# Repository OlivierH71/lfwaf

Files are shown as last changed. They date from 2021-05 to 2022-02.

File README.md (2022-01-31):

# lfwaf
Literally "Lightest filter wheel and focuser". This project aim to design a complete system based on indy library, Arduino like controller and 3D prints in order to get the less heavy focuser and filter wheel for Newton astro-photography.

In parralel to the Arduino code, an indi driver is developped under ~/Projects/indi/examples/lfwaf. You can refer to https://indilib.org/develop/developer-manual/163-setting-development-environment.html for indi driver dev 
To call the inidiserver during devlopment, use "indiserver -v ~/Projects/indi/examples/lfwaf/lfwaf" and open an indi client, I used Kstars. From Kstars, use "Tools|Device|Device Manager", Select "Client Tab" and a connection to the host (usualy localhost) on port 7624.

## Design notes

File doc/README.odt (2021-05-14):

lightest_focuserwheel

This project has been highly inspired by astroberry-diy (https://github.com/rkaczorek/astroberry-diy) and indi-wheel (https://github.com/Blueshawk/indi-wheel) .

Objective is to have the lightest setup with a minimum of cables to command diy focuser and diy filter wheel. Indeed, astroberry-diy focuser is a great use of raspberry pi connections but you need a minimum of 8 wires from pi to motor driver (MS1,MS2,MS3, GND, VDD, STEP, DIR and RST) and potentially 2 additional wires to connect buttons. So you need to know how-to build a good reliable and plugable 10 pin wire. RJ45 is a good candidate but if you connect the 8 pins to an RJ45 female, link to the focuser with RJ45 cable, and, then, same from driver and buttons, it becomes a little bit messy to connect. Additionally, you could do the same for the Wheel and all this becomes a cable nightmare.

My first idea was to use one of the USB connection and a USB to Serial cable to an Arduino device. As a direct consequence this enable the project to:

- Connect from any indi machine (not only rasperry device)
- Use BlueTooth as an alternative to USB cable as BlueTooth is also “seen” from the system as a serial port. If, like me, you have an astro setup with too many wires, and risk to block the mount tracking, each wire saving is an increase chance to follow correctly the stars.

As the weight is key, I also wanted to design a “3D” box which contains all arduino hardware, ie, the 2 stepper motors drivers, the optional connections to buttons and the Arduino device. This came to a choice, either to use an onboard BlueTooth device (ESP32) or an external BlueTooth connection (HC-05 for example). I ended up to do a system which can work with both.

Option ESP32

Install ESP32 board in arduino IDE: https://randomnerdtutorials.com/installing-the-esp32-board-in-arduino-ide-mac-and-linux-instructions/

For security (in case of ESP32 is replaced by different system), I have downloaded the files and instructions in ESP32. Use only in case of instructions in previous link does not work.

I used the ESP32-CAM version because… I had one :) Additionnaly this is the smallest version available at cheap cost and, why not, find a future use of the Camera feature

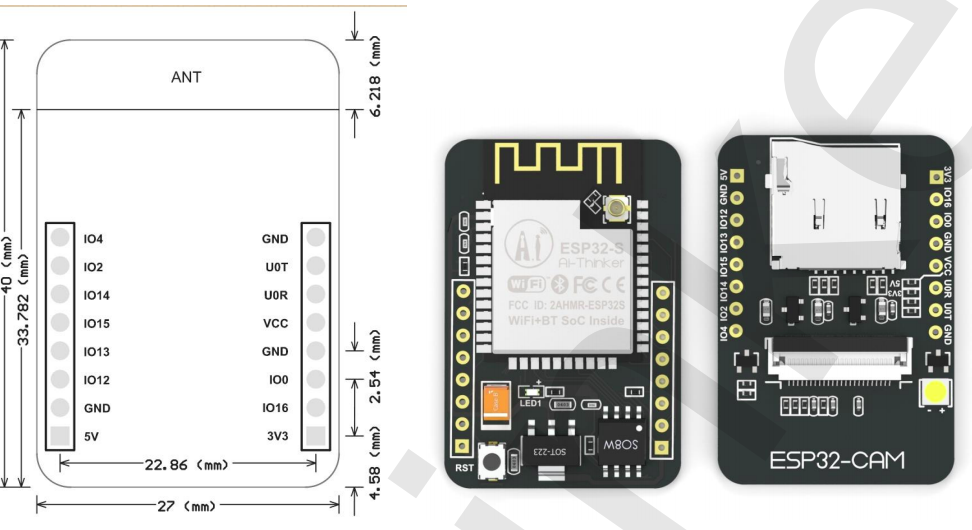
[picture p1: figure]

## The A4988 and stepper motor option

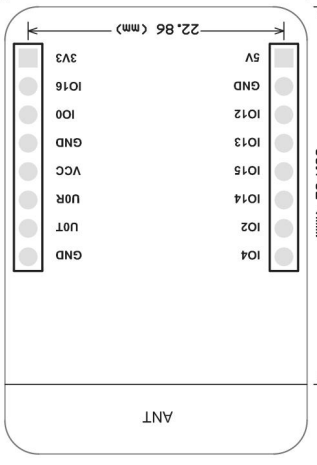
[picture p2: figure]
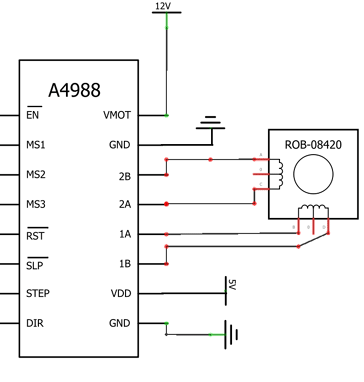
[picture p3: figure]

WARNING: Unlike what I initially thought, IO0 CANNOT BE USED. Connected to ground, this pin will put the ESP32 in Flashing mode.

The problem is the weight of the motors. A nema 17 weight is about 250g which, when installed at the end of my Newton telescope is really heavy, especially if you need two (one for the wheel and one for the focuser). Half a kilo does not deserve the “lightest” term.

Looking to different options, I found out that one of the lightest option I could find was a servo motor sg90 hacked to be able to turn endlessly, and this is only 14.5g. Speeking of “power”, sg90, because of its gearbox has a torque of 2.5kg/cm when the nema 17 is ‘only’ also 2.5kg/cm (well depends on model and available current. 2.5 seems an average of datasheets I found).

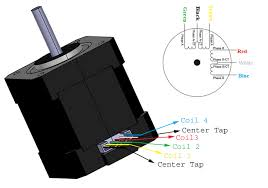
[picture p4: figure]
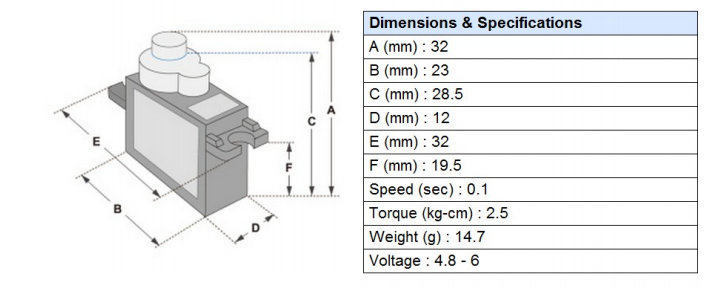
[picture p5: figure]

Nema 17: 250g for a Torque of 2.5kg/cm. Needs 12V to run and a specific “driver” | SG90: 14.5g for a Torque of 1.8kg/cm. Operates at 5V directly driven by micro-controller signal.

Another benefit is that you need only 1 power source (5V) to operate logic and motors while the first option requested a 12V and 5V power source. Finally, SG90 needs only 1 wire to control direction (the length of the impulsion sets the direction of the motor). This will free the UOT and UOR so we can keep them for a RS232 transmit only usage.

## The SG90 option

One of my concern using this option is the precision and the main outcome of the Hack which is finding the “0” position.

To make it short, this servo motor is using an internal potentiometer to know its position. With the “servo.h” arduino library, you encode a value between 0 and 180° which is converted to a signal sent to a wire.

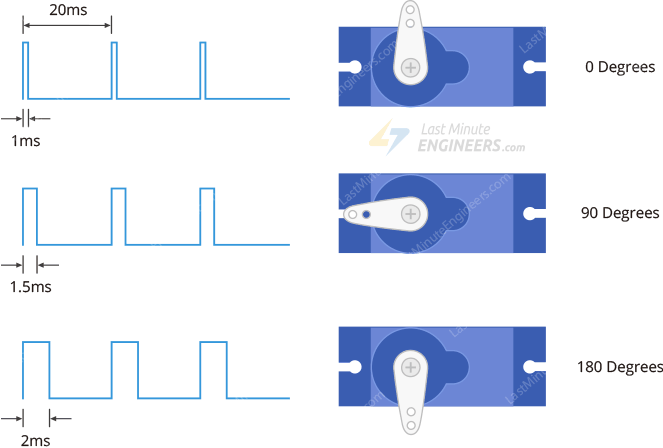
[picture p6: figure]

The internal circuitry converts back the signal to the desired position and turn until the internal potentiometer gives a tension which map to the correct angle.

With the hack, you hard remove the “stop” pin and, either replace the potentiometer with a bunch of fixed resistor or plug-in a power source and move the potentiometer until it stops spinning, then glue the potentiometer so it will not move.

For having read a lot and having experienced a little bit these devices I know that these cheap pieces are usually not very well tuned and that temperature or available current or V variation can change the “middle” value. This can also vary with time and oxidation of circuitry and its resistance, therefore, the hack makes it pretty complex to find the value to send to the servo if this value changes over time. As a result, not having the correct “middle” value introduce vibrations and even, sometime, un-sollicited moves.

The option will be to use the servo.attach() before and servo.detach() after each move, so the signal will just release the motor.

Another option could be to use one of the ESP32 pin to drive a NPN transistor to shut down the power source of the servo when we don’t need it to turn (99% of the time though).

### Option1: Attach/Detach in arduino sketch:

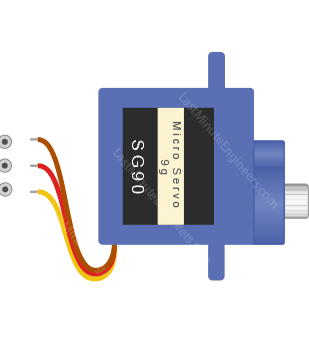
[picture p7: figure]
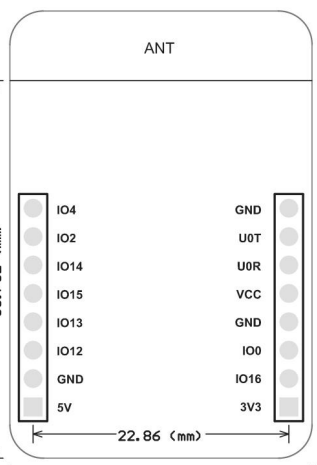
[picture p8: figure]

### Option2: NPN Driven power to enable/disable servos:

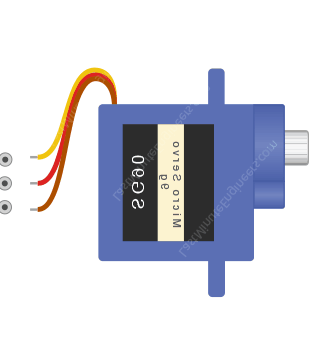
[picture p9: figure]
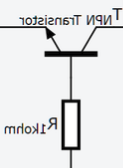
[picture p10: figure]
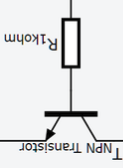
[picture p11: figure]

To enable both option, the 3D box has holes for 4 NPN transistors. Indeed, one transistor may not be enough to drain enough current for servo motor. Note that I have not planned holes for the 1kOhm resistors so to choose this option, resistors has to be placed between Transistor base and GPIO12 / GPIO13.

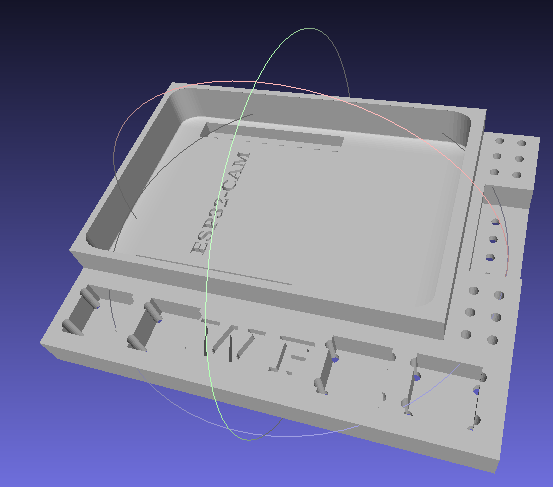
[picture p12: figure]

Wheel Buttons

ESP32 slot

2xNPN Slots

2xNPN Slots

4 pin connect

Focuser Buttons

Programming BlueTooth under Linux Ubuntu

Took here: http://tvaira.free.fr/bts-sn/activites/activite-ble/activite-ble-qt.html

ESP32 DevKit option

This option gives all advantages of previous solutions, it is still light, can be very low consuming (BLE), has a lot of possible wired which are for major part of them PWN and/or internally pull/up or Pull/down wired, which simplifies external wiring.

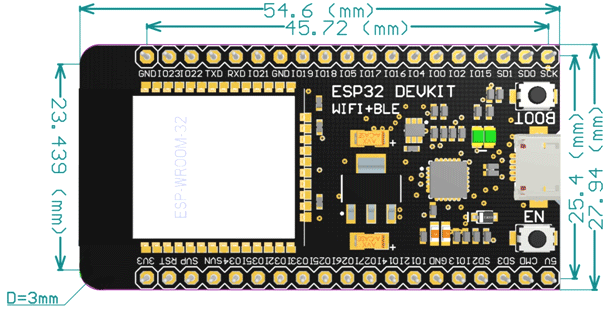
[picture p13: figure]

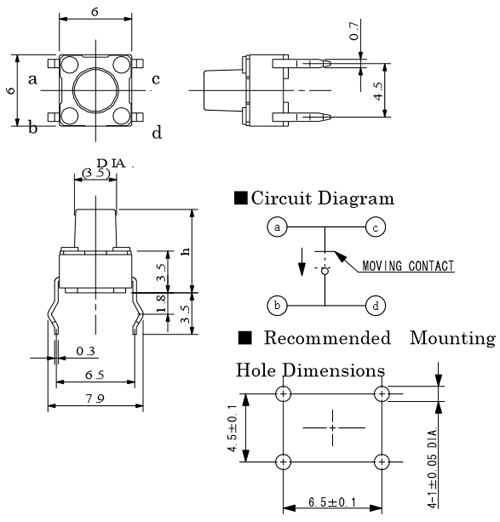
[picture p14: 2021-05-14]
doc/other/buttonDataSheet.png

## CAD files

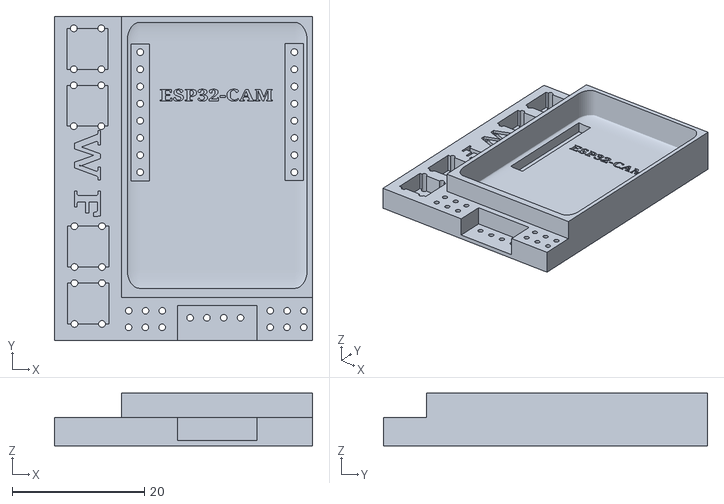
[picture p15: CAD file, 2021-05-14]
doc/SG90/lightFocuserwheel box - SG90.stl
39.0 x 49.0 x 8.00

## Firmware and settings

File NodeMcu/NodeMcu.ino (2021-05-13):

// #include<ESP8266WiFi> 
/*
 
*/

#include "lfwaf_logger.h"
#include "lfwaf_settings.h"
#include "lfwaf_wifi.h"
#include "lfwaf_helpers.h"

#define btnW_L_pin  D4
#define btnW_R_pin  D5
#define btnF_L_pin  D6
#define btnF_R_pin  D7

#define motW_L_pin  D0
#define motW_R_pin  D1
#define motF_L_pin  D2
#define motF_R_pin  D3

#define motorMinValue 135
#define motorMaxValue 1023

int cnvSpeed(int speed20){
  return (motorMaxValue-motorMinValue)/20 * speed20;
}


int speedW=cnvSpeed(10);
int speedF=cnvSpeed(10);
int wheelMove = 0;

lfwaf_logger _log(true);
lfwaf_settings _settings(&_log);

// Aftr an interrupt, we process what happened exactly
void processBtn( int btn, int Speed){
  //bool starting = false;
  // btnPressed
  if (digitalRead(btn) == LOW)
    //starting = true;
    switch(btn){
      case btnW_L_pin: wheelMove--; break;
      case btnW_R_pin: wheelMove++; break;
      case btnF_L_pin: analogWrite(motW_L_pin, cnvSpeed(_settings->values.focuserSpeed));break;
      case btnF_L_pin: analogWrite(motW_R_pin, cnvSpeed(_settings->values.focuserSpeed));break;
    }
   else
    switch(btn){
//      case btnW_L_pin: WheelMove--; break;  // nothing
//      case btnW_R_pin: WheelMove++; break;  // nothing
      case btnF_L_pin: analogWrite(motW_L_pin, 0);break;
      case btnF_L_pin: analogWrite(motW_R_pin, 0);break;
    }
}

// Handler for onboard buttons. We set one interrupt per button
void ICACHE_RAM_ATTR btnW_L_ISR(){ processBtn(btnW_L,_settings->values.fwSpeed); }
void ICACHE_RAM_ATTR btnW_L_ISR(){ processBtn(btnW_R,_settings->values.fwSpeed); }
void ICACHE_RAM_ATTR btnW_L_ISR(){ processBtn(btnF_L,_settings->values.focuserSpeed); }
void ICACHE_RAM_ATTR btnW_L_ISR(){ processBtn(btnF_R,_settings->values.focuserSpeed); }

void setup() {
  // Create logger
  _log.log(info, "lfwaf is starting");
  _log.log(debug, "setting pins");

  //configure pin 2 as an input and enable the internal pull-up resistor
  pinMode(btnW_L_pin, INPUT);
  pinMode(btnW_R_pin, INPUT);
  pinMode(btnF_L_pin, INPUT);
  pinMode(btnF_R_pin, INPUT);
  pinMode(motW_L_pin, OUTPUT);
  pinMode(motW_L_pin, OUTPUT);
  pinMode(motW_L_pin, OUTPUT);
  pinMode(motW_L_pin, OUTPUT);
  //Change frequency for PWM functions
  analogWriteFreq(50);

   // Set an interupt for each button
  attachInterrupt(digitalPinToInterrupt(btnW_L_pin),btnW_L_ISR,CHANGE);
  attachInterrupt(digitalPinToInterrupt(btnW_R_pin),btnW_R_ISR,CHANGE);
  attachInterrupt(digitalPinToInterrupt(btnF_L_pin),btnF_L_ISR,CHANGE);
  attachInterrupt(digitalPinToInterrupt(btnF_R_pin),btnF_R_ISR,CHANGE);
  
}

void loop() {
  //read the pushbutton value into a variable
  if (digitalRead(btnW_L_pin) == LOW){
    analogWrite(motW_L_pin,135);
  } else {
    analogWrite(motW_L_pin,0);
  }
  if (digitalRead(btnW_R_pin) == LOW){
    digitalWrite(LED_BUILTIN, LOW);
    analogWrite(motW_R_pin,1023);
  } else {
    digitalWrite(LED_BUILTIN, HIGH);
    analogWrite(motW_R_pin,0);
  }
}

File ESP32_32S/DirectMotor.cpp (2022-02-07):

#include "DirectMotor.h"

// use 13 bit precission for LEDC timer
#define LEDC_TIMER_13_BIT  13

// use 5000 Hz as a LEDC base frequency
#define LEDC_BASE_FREQ     50

void DirectMotor::setParams(uint8_t pin1, uint8_t pin2, uint8_t channel, DecayMode decayMode, NumOfPwmPins numPins)
{
  _pin1 = pin1; // always a PWM pin
  _pin2 = pin2; // can be a non-Pwm pin.
  _whichMode = decayMode;
  _numPwmPins = numPins;
//   _channel1 = channel*2;
//   _channel2 = _channel1+1;

//   // configure LED PWM functionalitites
//   ledcSetup(_channel1, LEDC_BASE_FREQ, LEDC_TIMER_13_BIT);
//   ledcSetup(_channel2, LEDC_BASE_FREQ, LEDC_TIMER_13_BIT);
//   /*ledcAttachPin(_channel1, _pin1);
//   ledcAttachPin(_channel2, _pin2); */
//   ledcAttachPin(_pin1, _channel1);
//   ledcAttachPin(_pin2, _channel2);
}

DirectMotor::DirectMotor( uint8_t pin1, uint8_t pin2, uint8_t channel) {
  setParams(pin1, pin2, channel, FAST_DECAY, PWM_2PIN);
}

DirectMotor::DirectMotor(uint8_t pin1, uint8_t pin2, uint8_t channel, DecayMode decayMode, NumOfPwmPins numPins) {
  setParams(pin1, pin2, channel, decayMode, numPins);
}

int DirectMotor::getPWM() {
  return _pwmVal;
}

void DirectMotor::stopMotor()
{
    digitalWrite(_pin1, LOW);
    digitalWrite(_pin2, LOW);
    _pwmVal = 0;
}

// Arduino like analogWrite
// value has to be between 0 and valueMax
// void DirectMotor::analogWrite(uint8_t channel, uint32_t value, uint32_t valueMax ) {
//   // calculate duty, 8191 from 2 ^ 13 - 1
//   uint32_t duty = (8191 / valueMax) * min(value, valueMax);
//   // write duty to LEDC
//   ledcWrite(channel, duty);
// }

void DirectMotor::startMotor(long pwmSpeed) {
  _pwmVal = pwmSpeed;
  if (pwmSpeed >0){
      digitalWrite(_pin1, LOW);
      digitalWrite(_pin2, HIGH);
  }
  else {
      digitalWrite(_pin2, LOW);
      digitalWrite(_pin1, HIGH);
  }
  
}

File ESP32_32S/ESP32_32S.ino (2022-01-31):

/*
  lfwaf using NodeMCU ESP32-32S
  This project relies on many classes:

  lfwaf_logger    logger class: it sends messages on different level to serial com' and Wifi link when connected
  lfwaf_settings  class relying on EEPROM. Stores settings locally in the MicroController (incl Wifi setting, speed and btns/motors IO pins)
  lfwaf_wifi      class based on Wifi class. Scans and connect to wifi.
  lfwaf_server    Action Server: handles queries sent to lfwaf. In Theory, could receive instructions from Wifi, serial or BLE and tells engine to operate
  lfwaf_engine    Hardware Engine: Manage buttons and motors actions
*/

#include "lfwaf_helpers.h"
#include "lfwaf_logger.h"
#include "lfwaf_settings.h"
#include "lfwaf_wifi.h"
#include "lfwaf_server.h"
#include "lfwaf_engine.h"

lfwaf_logger *_log;
lfwaf_settings *_settings;
lfwaf_wifi *_wifi;
lfwaf_server *_server;
lfwaf_engine *_engine;

/*************************************************************
                        ARDUINO SETUP
*************************************************************/
void setup()
{
  // Create logger
  _log = new lfwaf_logger(true);
  _log->log(info, "lfwaf is starting");
  _log->log(info, "Loading settings");
  _settings = new lfwaf_settings(_log);
  _log->log(info, "Settings loaded");

  _log->log(info, "Starting Wifi");
  _wifi = new lfwaf_wifi(_log, _settings);
  _wifi->connect();
  _log->log(info, "Wifi started");

  _log->log(info, "Starting Engine");
  _engine = new lfwaf_engine(_log, _settings);
  _log->log(info, "Engine started");

  _log->log(info, "Starting LFWAF Server");
  _server = new lfwaf_server(_log, _settings, _engine);
  _log->log(info, "LFWAF server started");
}
void nop()
{
}

/*************************************************************
                        ARDUINO LOOP
*************************************************************/
void loop()
{

  // Main loop is about server and engine: We always lookup for new clients and process inputs

  // Check for new client:
  _server->checkForClients();
  // Check for Manual buttons
  //_engine->checkManualBtns();
  // Check for remote commands
  _server->processInputs();
}

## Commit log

2021-05-14 Move docs
    [lightFocuserwheel box - SG90.stl]
2021-05-19 move to ESP32
2021-05-26 1st tests
    Crash when using Wifi AND buttons
    [ESP32_32S.ino, cntBtn.cpp, lfwaf_engine.cpp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]
2021-05-26 no GPIO Interrupt
